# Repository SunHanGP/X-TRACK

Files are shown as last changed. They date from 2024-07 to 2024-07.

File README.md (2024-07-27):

# Fork From X-TRACK
> 开源GPS自行车码表。
>
> **新增嘉立创PCB工程文件(2.0寸版本)**
>
> 拥有可显示实时位置的离线地图。
>
> 支持记录和显示实时轨迹以及导出标准GPX格式的轨迹文件。
>
> 全新设计的["页面生命周期管理"](https://github.com/FASTSHIFT/X-TRACK/tree/main/Software/X-Track/USER/App/Utils/PageManager)和["消息订阅发布框架"](https://github.com/FASTSHIFT/X-TRACK/tree/main/Software/X-Track/USER/App/Utils/DataCenter)。
>
> 演示视频：https://www.bilibili.com/video/BV1GB4y1K7VV



## GUI
> [LVGL V8](https://github.com/lvgl/lvgl)

## 硬件配置
* 1.主控: AT32F403ACGU7 (主频:240MHz RAM:224KB ROM:1MB)
* 2.屏幕: ST7789 IPS 1.54inch SPI接口 240x240分辨率 60Hz刷新率
* 3.储存器: Micro SD CARD 32GB 
* 4.输入设备: 旋转编码器
* 5.RTC: MCU内置RTC时钟
* 6.加速度计: LSM6DSM (支持硬件计步输出)
* 7.地磁计: LIS3MDL
* 8.GPS: ATGM336H (BDS + GPS + GLONASS + GALILEO + QZSS + SBAS)
* 9.电池: Li-ion 3.7V 683030 700mAh
* 10.电源管理: LP5907-3.3 + MCP73831
* 11.外壳: 3D打印 光固化

## 功能
* 1.支持速度、距离、时间、卡路里、航向显示
* 2.拥有**离线地图**，支持显示实时位置，支持缩放
* 3.支持计步
* 4.支持经纬度、海拔显示
* 5.支持RTC自动根据GPS校准
* 6.支持记录轨迹，可导出[GPX格式](https://zh.wikipedia.org/wiki/GPX)的文件
* 7.支持掉电自动保存数据(JSON格式文件)
* 8.四小时续航 (持续工作，始终亮屏)
* 9.支持在[PC模拟器](https://github.com/FASTSHIFT/X-TRACK/tree/main/Software/X-Track/Simulator)模拟，脱离硬件调试(配置为**Release x86**)
* 10.支持显示实时轨迹
* 11.待续...

## 实物演示
### 测速
https://user-images.githubusercontent.com/26767803/120889722-1f8d8e80-c631-11eb-8294-df79f151dedb.mp4

### 历史轨迹显示([GPXSee](https://github.com/tumic0/GPXSee))


## 致谢
> 感谢[@davidce](https://www.geek-workshop.com/home.php?mod=space&uid=204)贡献的参考设计“[自制基于arduino的GPS地图导航系统3.0](https://www.geek-workshop.com/thread-8835-1-1.html)”。

> 感谢[@W-Mai](https://github.com/W-Mai)改进的[地图下载链接生成工具](https://github.com/W-Mai/XLocateDownloader/releases/download/1.0.0/MapDownloader.zip)、[地图下载器](https://github.com/W-Mai/XLocateDownloader)、[LVGL图片转换器(Python版)](https://github.com/W-Mai/lvgl_image_converter)、[批量文件重命名工具](https://github.com/W-Mai/filename_renamer)。

> 感谢[@Trigger-CN](https://github.com/Trigger-CN)的[UI设计](https://github.com/FASTSHIFT/X-TRACK/tree/main/ArtDesign)。

> 感谢[@MouriNaruto](https://github.com/MouriNaruto)的LVGL Visual Studio模拟器[lv_sim_visual_studio](https://github.com/lvgl/lv_sim_visual_studio)。

> 感谢[@dj140](https://github.com/dj140)编写[地图下载教程](https://github.com/FASTSHIFT/X-TRACK/blob/main/Tools/README.md)。

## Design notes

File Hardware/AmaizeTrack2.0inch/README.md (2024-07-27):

# X-Track - 2.0英寸PCB，嘉立创版本
感谢@FASTSHIFT的开源项目X-TRACK
此版本PCB完全基于 [FASTSHIFT/X-TRACK/2.0-inch](https://github.com/FASTSHIFT/X-TRACK/tree/2.0-inch) 版本微调，**但采用嘉立创DEA专业版绘制，元件编号齐全，方便直接下单(PCB/SMT都可以)**

## 硬件改动基本与2.0跟原版的改动一致
* 使用四层PCB，方便走线，PCB厚度 *1.6mm*
* 主控芯片AT32F403ACGU7 QFN48pin6*6**（注意原2.0用的AT32F403ACGT7 LQFP48pin7\*7）**
* 串口线片更换为 *CP2102*
* IMU更换为 *MPU6050*
* 地磁极更换为 *QMC6310* **(换成QMC6310U，6310没买到)**
* 增加了电池电量计 *BQ27220*, 由于电量计是ROM-Base, 固件需要通过SD卡持久化保存电量计数据
* PCB接口由原来的焊盘更换为 *GH1.25*, 方便安装
* USB接口更换为Type-C
* 电源网络使用覆铜覆盖( [电池购买 523450](https://m.tb.cn/h.gRCxnBpw4CXNIVr?tk=aSf93cC6xcm ) )
* 充电芯片挪至PCB背面，可以更好的散热
* GPS模块内部集成了LDO, 因此将GPS模块VCC直接接电池减小*3.3v LDO*负载，**TX、RX串联一个100欧电阻**( [HT1818Z3G5L 购买地址](https://m.tb.cn/h.gRCCOYWMzNhfpTW?tk=wUBG3cCSN8j ) )
* 充电指示灯挪至边缘

## 注意事项
* 由于地线和电源线均采用覆铜走线，对烙铁焊接不够友好，建议使用 **低温锡膏** 加 **风枪** 方式焊接。
* 焊接最好使用延长排线加长屏幕排线，方便安装进外壳（**新增了14PIN插接款屏幕的PCB**）[插接屏2.0寸](https://m.tb.cn/h.gRCAggSShlwLRUn?tk=XvCI3cCREUD )
* ***BQ27220*** 电量计是可选项，BGA封装对焊接不够友好，新手不推荐安装（建议使用嘉立创的优惠券，有免费SMT订单）

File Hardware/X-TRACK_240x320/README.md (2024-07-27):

# X-Track - 2.0英寸PCB
感谢@FASTSHIFT的开源项目X-TRACK
此版本PCB布局参照[X-TRACK_LQFP](https://github.com/johnsbark/X-TRACK_LQFP)项目布局
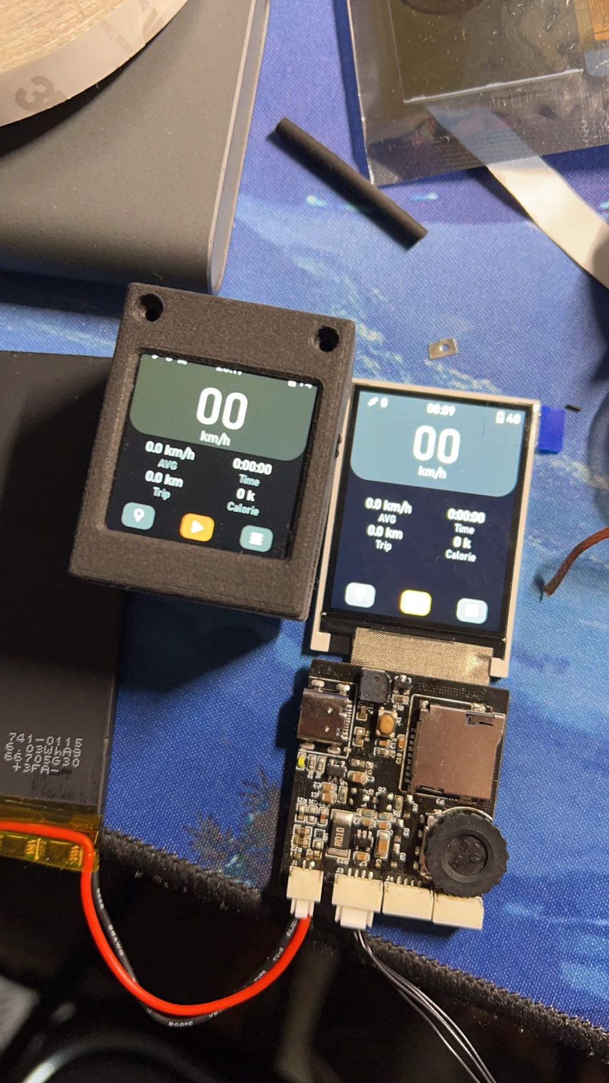
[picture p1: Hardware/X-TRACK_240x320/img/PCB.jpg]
2.0英寸PCB


## 硬件改动
* 使用四层PCB，方便走线，PCB厚度 *1.6mm*
* 串口线片更换为 *CP2102*
* IMU更换为 *MPU6050*
* 地磁极更换为 *QMC6310* (芯片封装极其不利于焊接，考虑之后替换为QMC5883)
* 增加了电池电量计 *BQ27220*, 由于电量计是ROM-Base, 固件需要通过SD卡持久化保存电量计数据
* PCB接口由原来的焊盘更换为 *GH1.25*, 方便安装
* USB接口更换为Type-C
* 电源网络使用覆铜覆盖
* 充电芯片挪至PCB背面，可以更好的散热
* GPS模块内部集成了LDO, 因此将GPS模块VCC直接接电池减小*3.3v LDO*负载
* 充电指示灯挪至边缘

## 注意事项
* 由于地线和电源线均采用覆铜走线，对烙铁焊接不够友好，建议使用 **低温锡膏** 加 **风枪** 方式焊接。
* 焊接最好使用延长排线加长屏幕排线，方便安装进外壳
* *BQ27220* 电量计是可选项，BGA封装对焊接不够友好，新手不推荐安装

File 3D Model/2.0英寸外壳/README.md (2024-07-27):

# X-Track - 2.0英寸屏幕外壳

***注：此版外壳集成了码表连接件，对模型强度有要求，光固化树脂3D打印模型韧度不够，推荐使用尼龙3D打印***

实物参考视频[X-Track Fork 2.0寸屏幕版本](https://www.bilibili.com/video/BV1Tb4y1i7N9#reply96403464928)

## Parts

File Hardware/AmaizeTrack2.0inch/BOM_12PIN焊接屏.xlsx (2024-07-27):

No. | Quantity | Comment | Designator | Footprint | Value | Manufacturer Part | Manufacturer | Supplier Part | Supplier | Primary Category | Secondary Category | Name | Symbol
1 | 1 | 4kHz | BUZZER1 | BUZ-SMD_FST-5030 | 4kHz | FUET-5030 | FUET(福声科技) | C391031 | LCSC |  |  | 4kHz | FST-5030
2 | 4 | 4.7uF | C1,C3,C17,C20 | C0603 | 4.7uF | CC0603KRX5R7BB475 | YAGEO(国巨) | C277476 | LCSC |  |  | 4.7uF | CL10A475KO8NNNC,CL21A475KBQNNNE,GRT188C81C475KE13D
3 | 13 | 100nF | C2,C4,C7,C8,C13,C18,C21,C22,C23,C24,C26,C27,C30 | C0603 | 100nF | CC0603KRX7R9BB104 | YAGEO(国巨) | C14663 | LCSC |  |  | 100nF | CapAcitance,CC0603KRX7R9BB104,CC0805KRX7R9BB104
4 | 1 | 10uF | C5 | C0603 | 10uF | CC0603MRX5R8BB106 | YAGEO(国巨) | C596327 | LCSC |  |  | 10uF | GRM21BR61H106KE43L
5 | 1 | 22uF | C6 | C1206 | 22uF | CC1206KKX5R8BB226 | YAGEO(国巨) | C2178233 | LCSC |  |  | 22uF | CL21A226MAQNNNE
6 | 7 | 1uF | C9,C10,C11,C12,C16,C25,C32 | C0603 | 1uF | CC0603KRX5R9BB105 | YAGEO(国巨) | C128624 | LCSC |  |  | 1uF | CapAcitance,CL10A105KB8NNNC
7 | 2 | 22pF | C14,C15 | C0603 | 22pF | CC0603JRNPO9BN220 | YAGEO(国巨) | C105620 | LCSC |  |  | 22pF | CapAcitance
8 | 2 | 2.2uF | C19,C31 | C0603 | 2.2uF | CC0603KRX5R7BB225 | YAGEO(国巨) | C106853 | LCSC |  |  | 2.2uF | CL10A225KO8NNNC,GRT188C81C225KE13D
9 | 1 | 2.2nF | C28 | C0603 | 2.2nF | CC0603KRX7R9BB222 | YAGEO(国巨) | C107082 | LCSC |  |  | 2.2nF | CapAcitance
10 | 1 | 10nF | C29 | C0603 | 10nF | CC0603KRX7R9BB103 | YAGEO(国巨) | C100042 | LCSC |  |  | 10nF | CL10A105KB8NNNC
11 | 1 | TF PUSH | CARD1 | TF-SMD_TF-PUSH |  | TF PUSH | SHOU HAN(首韩) | C393941 | LCSC |  |  | TF PUSH | TF-115-BCP9
12 | 1 | WAFER-GH1.25-2PWB | CN1 | CONN-TH_2P-P1.25_XUNPU_WAFER-GH1.25-2PWB |  | WAFER-GH1.25-2PWB | XUNPU(讯普) | C3029377 | LCSC | 连接器 | 线对板/线对线连接器 | WAFER-GH1.25-2PWB | WAFER-GH1.25-2PWB
13 | 4 | 1N4148WS | D2,D3,D4,D5 | SOD-323_L1.8-W1.3-LS2.5-RD |  | 1N4148WS | CJ(江苏长电/长晶) | C2128 | LCSC | 二极管 | 开关二极管 | 1N4148WS | 1N4148WS T4
14 | 1 | 1N4007WS | D6 | SOD-323_L1.8-W1.3-LS2.5-RD |  | 1N4007WS | MDD(辰达半导体) | C193404 | LCSC |  |  | 1N4007WS | 1N4007_C727082
15 | 1 | SCREEN 2.0' | LCD1 | SCREEN 2.0' 12PIN |  |  |  |  |  |  |  | SCREEN 2.0' | 2.0-TFT-IPS
16 | 1 | SZYY0603R | LED1 | LED0603-R-RD |  | SZYY0603R | yongyu(永裕光电) | C434419 | LCSC | 光电器件 | 发光二极管/LED | SZYY0603R | SZYY0603R
17 | 1 | AO3401 | Q1 | SOT-23-3_L2.9-W1.4-P1.90-LS2.6-BR |  | AO3401 | TWGMC(台湾迪嘉) | C727156 | LCSC | 三极管/MOS管/晶体管 | 场效应管(MOSFET) | AO3401 | AO3401_C727156
18 | 3 | AO3400 | Q2,Q3,Q4 | SOT-23-3_L2.9-W1.3-P1.90-LS2.4-BR |  | AO3400 | Hottech(合科泰) | C181090 | LCSC | 三极管/MOS管/晶体管 | 场效应管(MOSFET) | AO3400 | AO3400_C181090
19 | 1 | 2kΩ | R1 | R0603 | 2kΩ | 0603WAF2001T5E | UNI-ROYAL(厚声) | C22975 | LCSC |  |  | 2kΩ | 电阻
20 | 1 | 1kΩ | R2 | R0603 | 1kΩ | 0603WAF1001T5E | UNI-ROYAL(厚声) | C21190 | LCSC |  |  | 1kΩ | 电阻
21 | 4 | 20kΩ | R3,R4,R5,R6 | R0603 | 20kΩ | 0603WAF2002T5E | UNI-ROYAL(厚声) | C4184 | LCSC |  |  | 20kΩ | 电阻
22 | 13 | 10kΩ | R7,R8,R11,R13,R14,R15,R16,R19,R20,R21,R22,R24,R26 | R0603 | 10kΩ | 0603WAF1002T5E | UNI-ROYAL(厚声) | C25804 | LCSC |  |  | 10kΩ | 0603WAF1002T5E,0805W8F1002T5E,电阻
23 | 4 | 100Ω | R9,R10,R27,R28 | R0603 | 100Ω | 0603WAF1000T5E | UNI-ROYAL(厚声) | C22775 | LCSC |  |  | 100Ω | 0603WAF1000T5E,电阻
24 | 1 | 10Ω | R12 | R0603 | 10Ω | 0603WAF100JT5E | UNI-ROYAL(厚声) | C22859 | LCSC |  |  | 10Ω | 电阻
25 | 2 | 5.1kΩ | R17,R18 | R0603 | 5.1kΩ | 0603WAF5101T5E | UNI-ROYAL(厚声) | C23186 | LCSC |  |  | 5.1kΩ | 电阻
26 | 1 | 0Ω | R23 | R2512 | 0Ω | 25121WF0000T4E | UNI-ROYAL(厚声) | C270957 | LCSC |  |  | 0Ω | 0402WGF499JTCE
27 | 1 | SDNT1608X103F3380FTF | R25 | R0603 |  | SDNT1608X103F3380FTF | Sunlord(顺络) | C316397 | LCSC |  |  | SDNT1608X103F3380FTF | SDNT2012X103F3950FTF
28 | 1 | AT32F403ACGU7 | U1 | QFN-48_L6.0-W6.0-P0.40-BL-EP4.2 |  | AT32F403ACGU7 | ARTERY(雅特力) | C528438 | LCSC | 单片机/微控制器 | 单片机(MCU/MPU/SOC) | AT32F403ACGU7 | AT32F403ACGU7
29 | 1 | QMC6310U | U2 | LGA-8_L1.2-W1.2-P0.40-R3-C3-TL |  | QMC6310U | QST(上海矽睿) | C669299 | LCSC | 传感器 | 霍尔传感器 | QMC6310U | QMC6310
30 | 3 | WAFER-GH1.25-4PWB | U3,U4,U5 | CONN-SMD_4P-P1.25_XUNPU_WAFER-GH1.25-4PWB |  | WAFER-GH1.25-4PWB | XUNPU(讯普) | C3029379 | LCSC | 连接器 | 线对板针座 | WAFER-GH1.25-4PWB | WAFER-GH1.25-4PWB
31 | 1 | USB-TYPE-C-016 | U7 | USB-SMD_TYPE-C16PCB1.6073 |  | USB-TYPE-C-016 | DEALON(德艺隆) | C2927036 | LCSC | 连接器 | USB连接器 | USB-TYPE-C-016 | USB-TYPE-C-016
32 | 1 | MPU-6050 | U8 | QFN-24_L4.0-W4.0-P0.50-BL-EP2.7 |  | MPU-6050 | TDK InvenSense(应美盛) | C24112 | LCSC | 传感器 | 姿态传感器/陀螺仪 | MPU-6050 | MPU-6050_C24112
33 | 1 | CP2102-GMR | U9 | WQFN-28_L5.0-W5.0-P0.50-BL-EP3.2 |  | CP2102-GMR | SKYWORKS/SILICON LABS(芯科) | C6568 | LCSC | 通信接口芯片 | USB转换芯片 | CP2102-GMR | CP2102-GMR
34 | 1 | SIQ-02FVS3 | U10 | SW-SMD_SIQ-02FVS3_1 |  | SIQ-02FVS3 | MITSUMI(美上美) | C2925423 | LCSC | 按键/开关 | 旋转编码器 | SIQ-02FVS3 | SIQ-02FVS3
35 | 1 | MCP73831T-2ACI/OT | U11 | SOT-23-5_L3.0-W1.7-P0.95-LS2.8-BL |  | MCP73831T-2ACI/OT | MICROCHIP(美国微芯) | C424093 | LCSC |  |  | MCP73831T-2ACI/OT | MCP73831T-2ACI/OT
36 | 1 | LP5907MFX-3.3/NOPB | U12 | SOT-23-5_L3.0-W1.7-P0.95-LS2.8-BR |  | LP5907MFX-3.3/NOPB | TI(德州仪器) | C80670 | LCSC | 电源管理 | 线性稳压器(LDO) | LP5907MFX-3.3/NOPB | LP5907MFX-3.3/NOPB
37 | 1 | BQ27220YZFR | U13 | DSBGA-9_L1.7-W1.6-R3-C3-P0.50-BL |  | BQ27220YZFR | TI(德州仪器) | C528617 | LCSC | 电源管理 | 电池管理 | BQ27220YZFR | BQ27220
38 | 1 | ZX-QC34-2TPDZ | U14 | KEY-SMD_L3.9-W3.0-LS5.0-EH |  | ZX-QC34-2TPDZ | Megastar(兆星) | C7470219 | LCSC | 按键/开关 | 轻触开关 | ZX-QC34-2TPDZ | ZX-QC34-2TPDZ
39 | 1 | 32.768kHz | Y1 | FC-135R_L3.2-W1.5 | 32.768kHz | Q13FC13500004 | EPSON(爱普生) | C32346 | LCSC | 振荡器/谐振器 | 无源晶振 | 32.768kHz | Q13FC1350000400

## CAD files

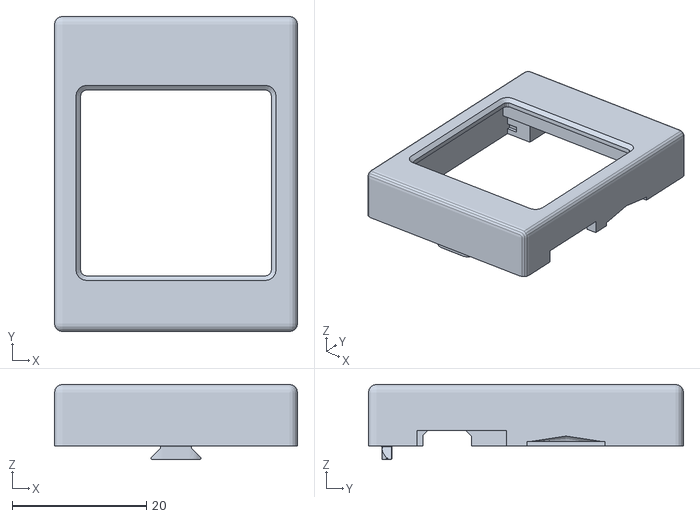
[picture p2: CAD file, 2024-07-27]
3D Model/1.5英寸外壳/top.stl
36.3 x 47.0 x 11.2

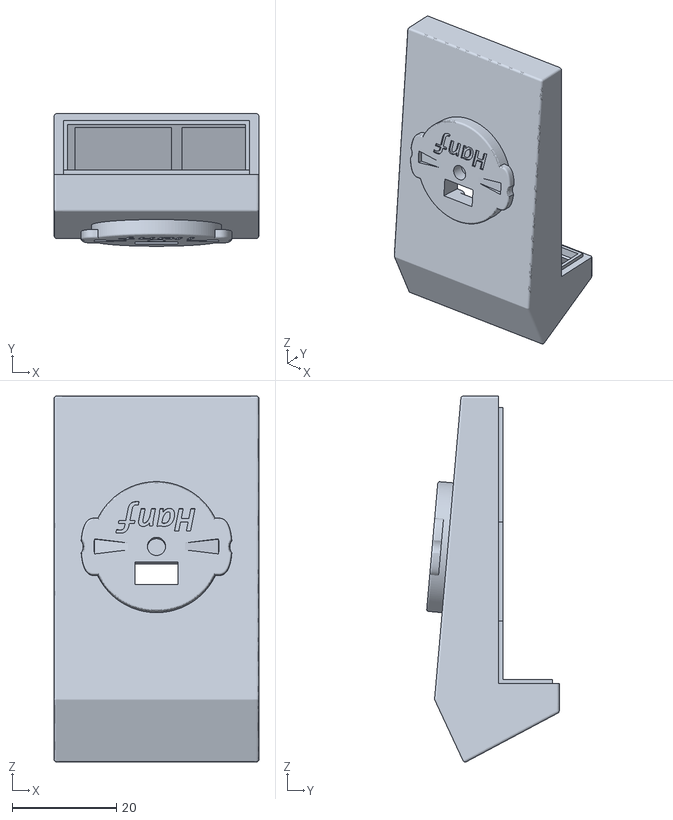
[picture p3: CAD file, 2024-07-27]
3D Model/2.0英寸外壳/bottom.stl
39.3 x 25.4 x 70.2

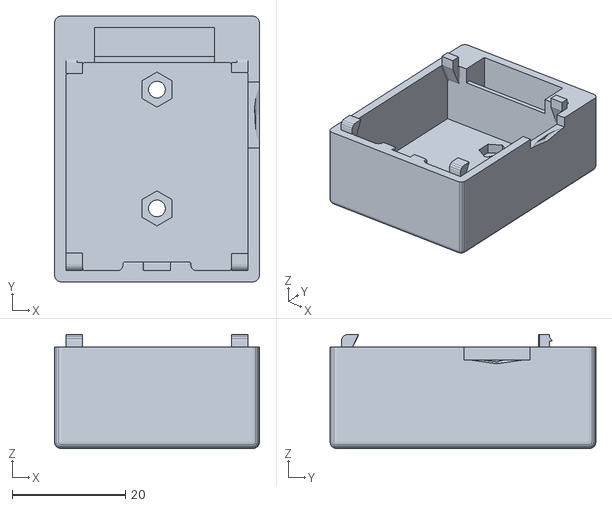
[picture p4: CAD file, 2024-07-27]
3D Model/1.5英寸外壳/bottom.stl
36.3 x 47.0 x 20.2

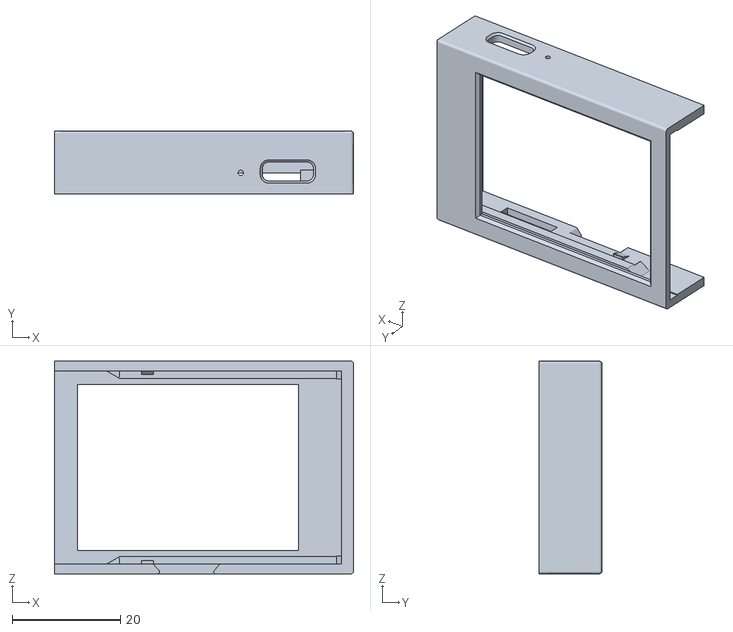
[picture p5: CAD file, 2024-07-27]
3D Model/2.0英寸外壳/top.stl
55.2 x 11.6 x 39.3

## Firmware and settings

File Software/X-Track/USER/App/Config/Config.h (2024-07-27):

/*
 * MIT License
 * Copyright (c) 2021 _VIFEXTech
 *
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
 * THE SOFTWARE IS PROVIDED "AS IS", WITHOUT WARRANTY OF ANY KIND, EXPRESS OR
 * IMPLIED, INCLUDING BUT NOT LIMITED TO THE WARRANTIES OF MERCHANTABILITY,
 * FITNESS FOR A PARTICULAR PURPOSE AND NONINFRINGEMENT. IN NO EVENT SHALL THE
 * AUTHORS OR COPYRIGHT HOLDERS BE LIABLE FOR ANY CLAIM, DAMAGES OR OTHER
 * LIABILITY, WHETHER IN AN ACTION OF CONTRACT, TORT OR OTHERWISE, ARISING FROM,
 * OUT OF OR IN CONNECTION WITH THE SOFTWARE OR THE USE OR OTHER DEALINGS IN THE
 * SOFTWARE.
 */
#ifndef __CONFIG_H
#define __CONFIG_H

/*=========================
   Application configuration
 *=========================*/

#define CONFIG_SYSTEM_SAVE_FILE_PATH          "/SystemSave.json"
#define CONFIG_SYSTEM_SAVE_FILE_BACKUP_PATH   "/.SystemSaveBackup.json"
#define CONFIG_SYSTEM_LANGUAGE_DEFAULT        "en-GB"
#define CONFIG_SYSTEM_TIME_ZONE_DEFAULT       8    // GMT+ 8
#define CONFIG_SYSTEM_SOUND_ENABLE_DEFAULT    true

#define CONFIG_WEIGHT_DEFAULT                 65   // kg

#ifdef ARDUINO
#  define CONFIG_GPS_REFR_PERIOD              1000 // ms
#else
#  define CONFIG_GPS_REFR_PERIOD              10 // ms
#endif

#define CONFIG_GPS_LONGITUDE_DEFAULT          104.072237f
#define CONFIG_GPS_LATITUDE_DEFAULT           30.663537f

#define CONFIG_TRACK_FILTER_OFFSET_THRESHOLD  2 // pixel
#define CONFIG_TRACK_RECORD_FILE_DIR_NAME     "Track"

#define CONFIG_MAP_USE_WGS84_DEFAULT          false
#define CONFIG_MAP_DIR_PATH_DEFAULT           "/MAP"

#ifndef CONFIG_MAP_EXT_NAME_DEFAULT
#define CONFIG_MAP_EXT_NAME_DEFAULT           "bin"
#endif

#ifndef CONFIG_MAP_IMG_PNG_ENABLE
#  define CONFIG_MAP_IMG_PNG_ENABLE           0
#endif

#define CONFIG_GAUGE_DESIGN_CAP_DEFAULT       1200
#define CONFIG_GAUGE_FULL_CHG_CAP_DEFAULT     1200

#define CONFIG_ARROW_THEME_DEFAULT            "default"

#define CONFIG_LIVE_MAP_LEVEL_DEFAULT         16

#define CONFIG_LIVE_MAP_DEBUG_ENABLE          0
#if CONFIG_LIVE_MAP_DEBUG_ENABLE
#  define CONFIG_LIVE_MAP_VIEW_WIDTH          240
#  define CONFIG_LIVE_MAP_VIEW_HEIGHT         240
#else
#  define CONFIG_LIVE_MAP_VIEW_WIDTH          LV_HOR_RES
#  define CONFIG_LIVE_MAP_VIEW_HEIGHT         LV_VER_RES
#endif

#define CONFIG_MONKEY_TEST_ENABLE             0
#if CONFIG_MONKEY_TEST_ENABLE
#  define CONFIG_MONKEY_INDEV_TYPE            LV_INDEV_TYPE_ENCODER
#  define CONFIG_MONKEY_PERIOD_MIN            10
#  define CONFIG_MONKEY_PERIOD_MAX            100
#  define CONFIG_MONKEY_INPUT_RANGE_MIN       -5
#  define CONFIG_MONKEY_INPUT_RANGE_MAX       5
#endif

#endif

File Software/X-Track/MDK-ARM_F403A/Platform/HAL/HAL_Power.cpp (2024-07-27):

#include "HAL/HAL.h"

#if CONFIG_LIPO_FUEL_GAUGE_ENABLE

#include "BQ27220/BQ27220.h"
static BQ27220 fuel_gauge;
#endif

#define BATT_ADC                    ADC1
#define BATT_MIN_VOLTAGE            3300
#define BATT_MAX_VOLTAGE            4200
#define BATT_FULL_CHARGE_VOLTAGE    4100

#if CONFIG_POWER_BATT_CHG_DET_PULLUP
#  define BATT_CHG_DET_PIN_MODE     INPUT_PULLUP
#  define BATT_CHG_DET_STATUS       (!digitalRead(CONFIG_BAT_CHG_DET_PIN))
#else
#  define BATT_CHG_DET_PIN_MODE     INPUT_PULLDOWN
#  define BATT_CHG_DET_STATUS       ((info->usage == 100) ? false : digitalRead(CONFIG_BAT_CHG_DET_PIN))
#endif

typedef struct
{
    uint32_t LastHandleTime;
    uint16_t AutoLowPowerTimeout;
    bool AutoLowPowerEnable;
    bool ShutdownReq;
    uint16_t ADCValue;
    HAL::Power_CallbackFunction_t EventCallback;
} Power_t;

static Power_t Power;

#if CONFIG_LIPO_FUEL_GAUGE_ENABLE
static void Power_ADC_Init(void)
{
    fuel_gauge.init();
    fuel_gauge.refreshData();
#else
static void Power_ADC_Init(ADC_Type* ADCx)
{
    RCC_APB2PeriphClockCmd(RCC_APB2PERIPH_ADC1, ENABLE);
    RCC_ADCCLKConfig(RCC_APB2CLK_Div8);

    ADC_Reset(ADCx);

    ADC_InitType ADC_InitStructure;
    ADC_StructInit(&ADC_InitStructure);
    ADC_InitStructure.ADC_Mode = ADC_Mode_Independent;
    ADC_InitStructure.ADC_ScanMode = DISABLE;
    ADC_InitStructure.ADC_ContinuousMode = DISABLE;
    ADC_InitStructure.ADC_ExternalTrig = ADC_ExternalTrig_None;
    ADC_InitStructure.ADC_DataAlign = ADC_DataAlign_Right;
    ADC_InitStructure.ADC_NumOfChannel = 1;
    ADC_Init(ADCx, &ADC_InitStructure);

    ADC_ClearFlag(ADCx, ADC_FLAG_EC);

    ADC_Ctrl(ADCx, ENABLE);
    ADC_RstCalibration(ADCx);
    while(ADC_GetResetCalibrationStatus(ADCx));
    ADC_StartCalibration(ADCx);
    while(ADC_GetCalibrationStatus(ADCx));
}
#endif
}

#if !CONFIG_LIPO_FUEL_GAUGE_ENABLE
static uint16_t Power_ADC_GetValue()
{
    uint16_t retval = 0;
    if(ADC_GetFlagStatus(BATT_ADC, ADC_FLAG_EC))
    {
        retval = ADC_GetConversionValue(BATT_ADC);
    }
    return retval;
}
#endif
static void Power_ADC_Update()
{

#if CONFIG_LIPO_FUEL_GAUGE_ENABLE
    fuel_gauge.refreshData();
#else
    static bool isStartConv = false;

    if(!isStartConv)
    {
        ADC_RegularChannelConfig(
            BATT_ADC,
            PIN_MAP[CONFIG_BAT_DET_PIN].ADC_Channel,
            1,
            ADC_SampleTime_41_5
        );
        ADC_SoftwareStartConvCtrl(BATT_ADC, ENABLE);
        isStartConv = true;
    }
    else
    {
        Power.ADCValue = Power_ADC_GetValue();
        isStartConv = false;
    }
#endif
}

void HAL::Power_Init()
{
    memset(&Power, 0, sizeof(Power));
    Power.AutoLowPowerTimeout = 60;

    Serial.printf("Power: Waiting[%dms]...\r\n", CONFIG_POWER_WAIT_TIME);
    pinMode(CONFIG_POWER_EN_PIN, OUTPUT);
    digitalWrite(CONFIG_POWER_EN_PIN, LOW);
    delay(CONFIG_POWER_WAIT_TIME);
    digitalWrite(CONFIG_POWER_EN_PIN, HIGH);
    Serial.println("Power: ON");


#if !CONFIG_LIPO_FUEL_GAUGE_ENABLE
    Power_ADC_Init(BATT_ADC);
    pinMode(CONFIG_BAT_DET_PIN, INPUT_ANALOG);

//    Power_SetAutoLowPowerTimeout(5 * 60);
//    Power_HandleTimeUpdate();
    Power_SetAutoLowPowerEnable(false);
#else
    Power_ADC_Init();
    pinMode(CONFIG_BAT_CHG_DET_PIN, BATT_CHG_DET_PIN_MODE);
    Power_SetAutoLowPowerTimeout(60);
    Power_HandleTimeUpdate();
    Power_SetAutoLowPowerEnable(true);
#endif
}

void HAL::Power_HandleTimeUpdate()
{
    Power.LastHandleTime = millis();
}

void HAL::Power_SetAutoLowPowerTimeout(uint16_t sec)
{
    Power.AutoLowPowerTimeout = sec;
}

uint16_t HAL::Power_GetAutoLowPowerTimeout()
{
    return Power.AutoLowPowerTimeout;
}

void HAL::Power_SetAutoLowPowerEnable(bool en)
{
    Power.AutoLowPowerEnable = en;
    Power_HandleTimeUpdate();
}

void HAL::Power_Shutdown()
{
    CM_EXECUTE_ONCE(Power.ShutdownReq = true);
}

void HAL::Power_Update()
{
    CM_EXECUTE_INTERVAL(Power_ADC_Update(), 1000);

    if(!Power.AutoLowPowerEnable)
        return;

#if CONFIG_LIPO_FUEL_GAUGE_ENABLE
    if((!fuel_gauge.should_power_off) && fuel_gauge.voltage > BATT_MIN_VOLTAGE)
    {
        Power_HandleTimeUpdate();
    }
#endif

    if(Power.AutoLowPowerTimeout == 0)
        return;

    if(millis() - Power.LastHandleTime >= (Power.AutoLowPowerTimeout * 1000))
    {
        Power_Shutdown();
    }
}

void HAL::Power_EventMonitor()
{
    if(Power.ShutdownReq)
    {
        if(Power.EventCallback)
        {
            Power.EventCallback();
        }
        Backlight_SetGradual(0, 500);
        digitalWrite(CONFIG_POWER_EN_PIN, LOW);
        Serial.println("Power: OFF");
        Power.ShutdownReq = false;
    }
}

void HAL::Power_GetInfo(Power_Info_t* info)
{
#if !CONFIG_LIPO_FUEL_GAUGE_ENABLE
    int voltage = map(
                      Power.ADCValue,
                      0, 4095,
                      0, 3300
                  );

    voltage *= 2;

    CM_VALUE_LIMIT(voltage, BATT_MIN_VOLTAGE, BATT_MAX_VOLTAGE);

    int usage = map(
                    voltage,
                    BATT_MIN_VOLTAGE, BATT_FULL_CHARGE_VOLTAGE,
                    0, 100
                );

    CM_VALUE_LIMIT(usage, 0, 100);

    info->usage = usage;
    info->isCharging = BATT_CHG_DET_STATUS;
    info->voltage = voltage;
#else
    info->voltage = fuel_gauge.voltage;
    info->usage = uint8_t(fuel_gauge.remaining_capacity * 100.0 / fuel_gauge.fullcharge_capacity);
    info->isCharging = BATT_CHG_DET_STATUS && (fuel_gauge.battery_status == BQ27220::CHARGING || fuel_gauge.battery_status == BQ27220::FULL);
    if (info->isCharging)
    {
        info->time_to = fuel_gauge.time_to_full;
    }
    else
    {
        info->time_to = fuel_gauge.time_to_empty;
    }
    info->fullcharge_capacity = fuel_gauge.fullcharge_capacity;
    info->design_capacity = fuel_gauge.design_capacity;
    info->remaining_capacity = fuel_gauge.remaining_capacity;
    info->current = fuel_gauge.current;
    info->average_power = fuel_gauge.average_power;
#endif
}

void HAL::Power_RevertCapacity(uint16_t designCapacity, uint16_t fullChargeCapacity)
{
#if CONFIG_LIPO_FUEL_GAUGE_ENABLE
    fuel_gauge.setCapacity(designCapacity, fullChargeCapacity);
#endif
}

void HAL::Power_SetEventCallback(Power_CallbackFunction_t callback)
{
    Power.EventCallback = callback;
}
